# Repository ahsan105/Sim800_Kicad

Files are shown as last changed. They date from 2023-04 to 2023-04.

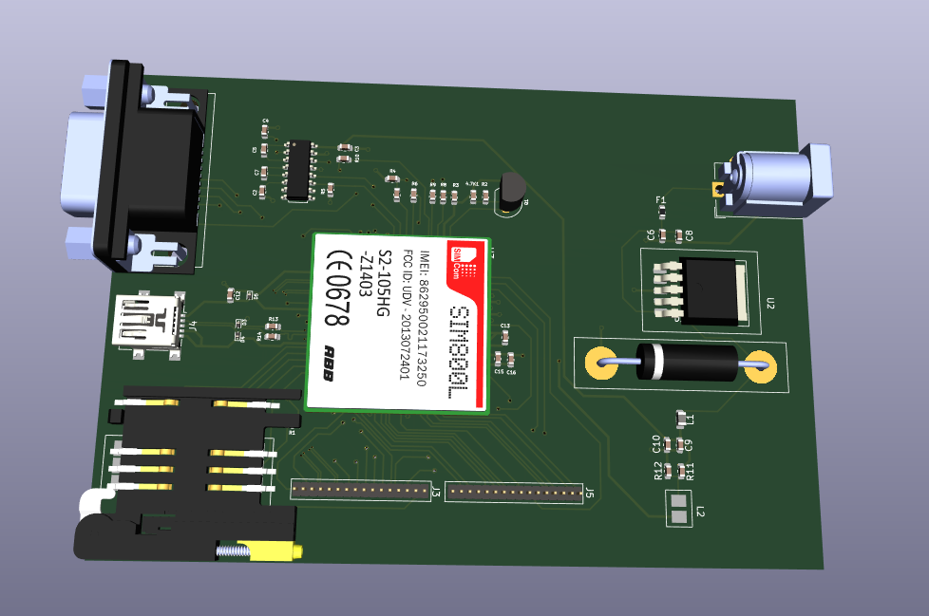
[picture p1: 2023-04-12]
3D_Image_of_project.png

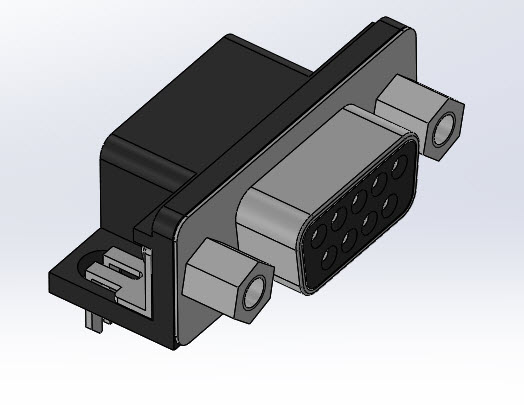
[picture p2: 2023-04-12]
db9-rs232-1.snapshot.3/Renderings/12-10-2558 9-55-57.jpg

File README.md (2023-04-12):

# Sim800_Kicad
This project is a hobby project (make sure you read the Readme file). The board hosts Sim800 IC that provides the GPRS capabilities to the board and added different 
serial protocols to provide ease of connection. Also the board has a power supply design that converts the output to 4.4V that goes to the IC.

Dont use this board directly. Make sure you consult your fabricator and change the clearance of differential pairs and also thickness.

Consult your fabricator and according to that set the via size and annular ring. 

Adjust the soldermask and other layers spacing according to it. 

Add an ESD peotection with sim interface.

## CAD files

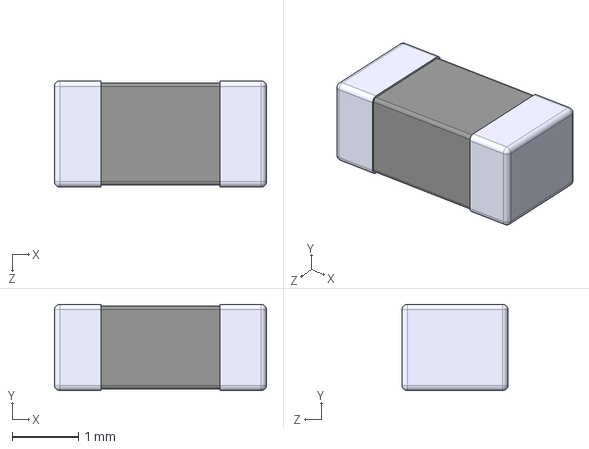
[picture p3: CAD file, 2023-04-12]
BLM31PG121SN1L/BLM31PG121SN1L.step
3.20 x 1.30 x 1.60 mm

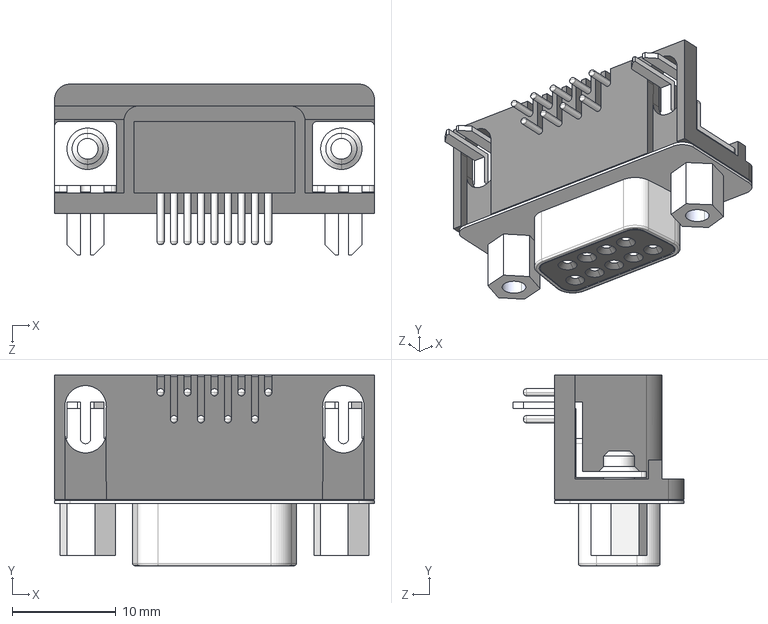
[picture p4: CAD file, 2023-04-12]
db9-rs232-1.snapshot.3/DB9.STEP
30.9 x 18.4 x 16.5 mm

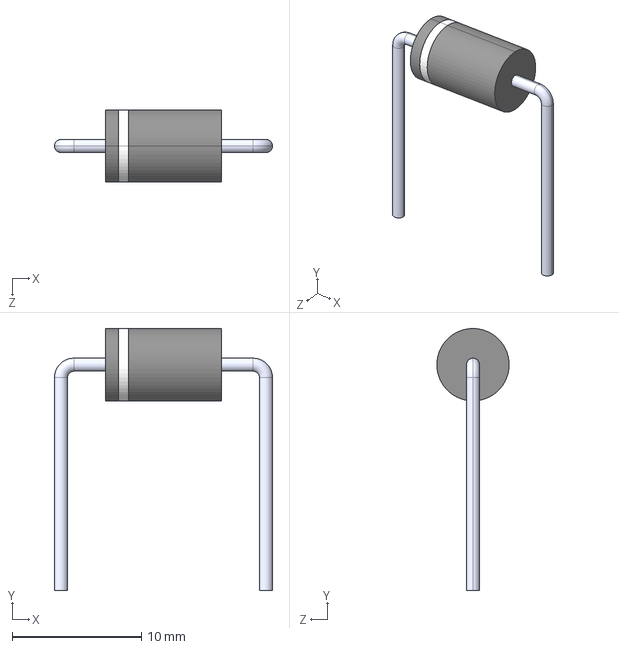
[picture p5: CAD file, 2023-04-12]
MBR360.STEP
16.9 x 20.3 x 5.60 mm

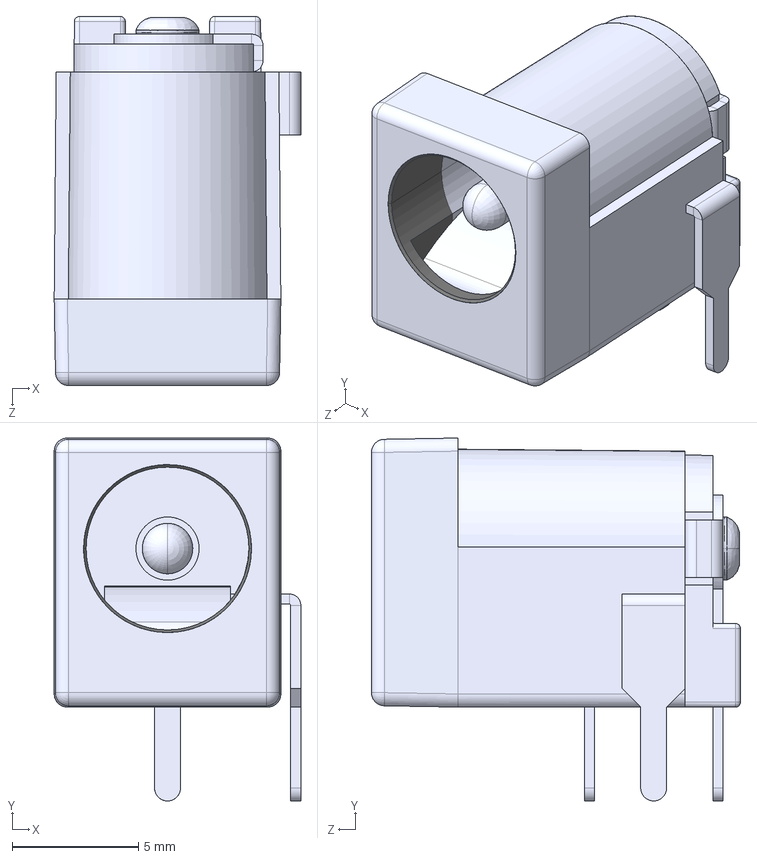
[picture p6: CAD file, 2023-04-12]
DC Power Jack 5.5mm x 2.1mm.IGS
9.77 x 14.4 x 14.6 mm

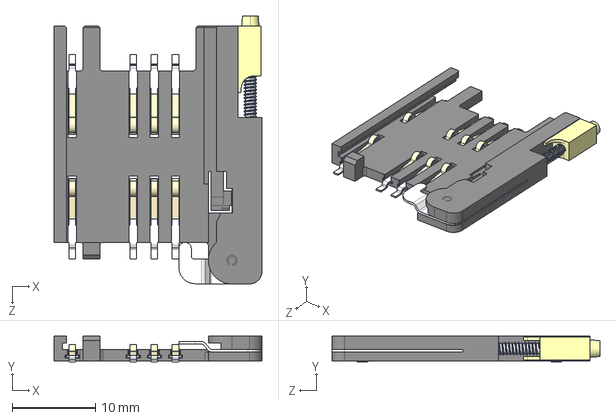
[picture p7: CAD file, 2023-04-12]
91228-3001--3DModel-STEP-56544.STEP
25.0 x 3.10 x 32.2 mm

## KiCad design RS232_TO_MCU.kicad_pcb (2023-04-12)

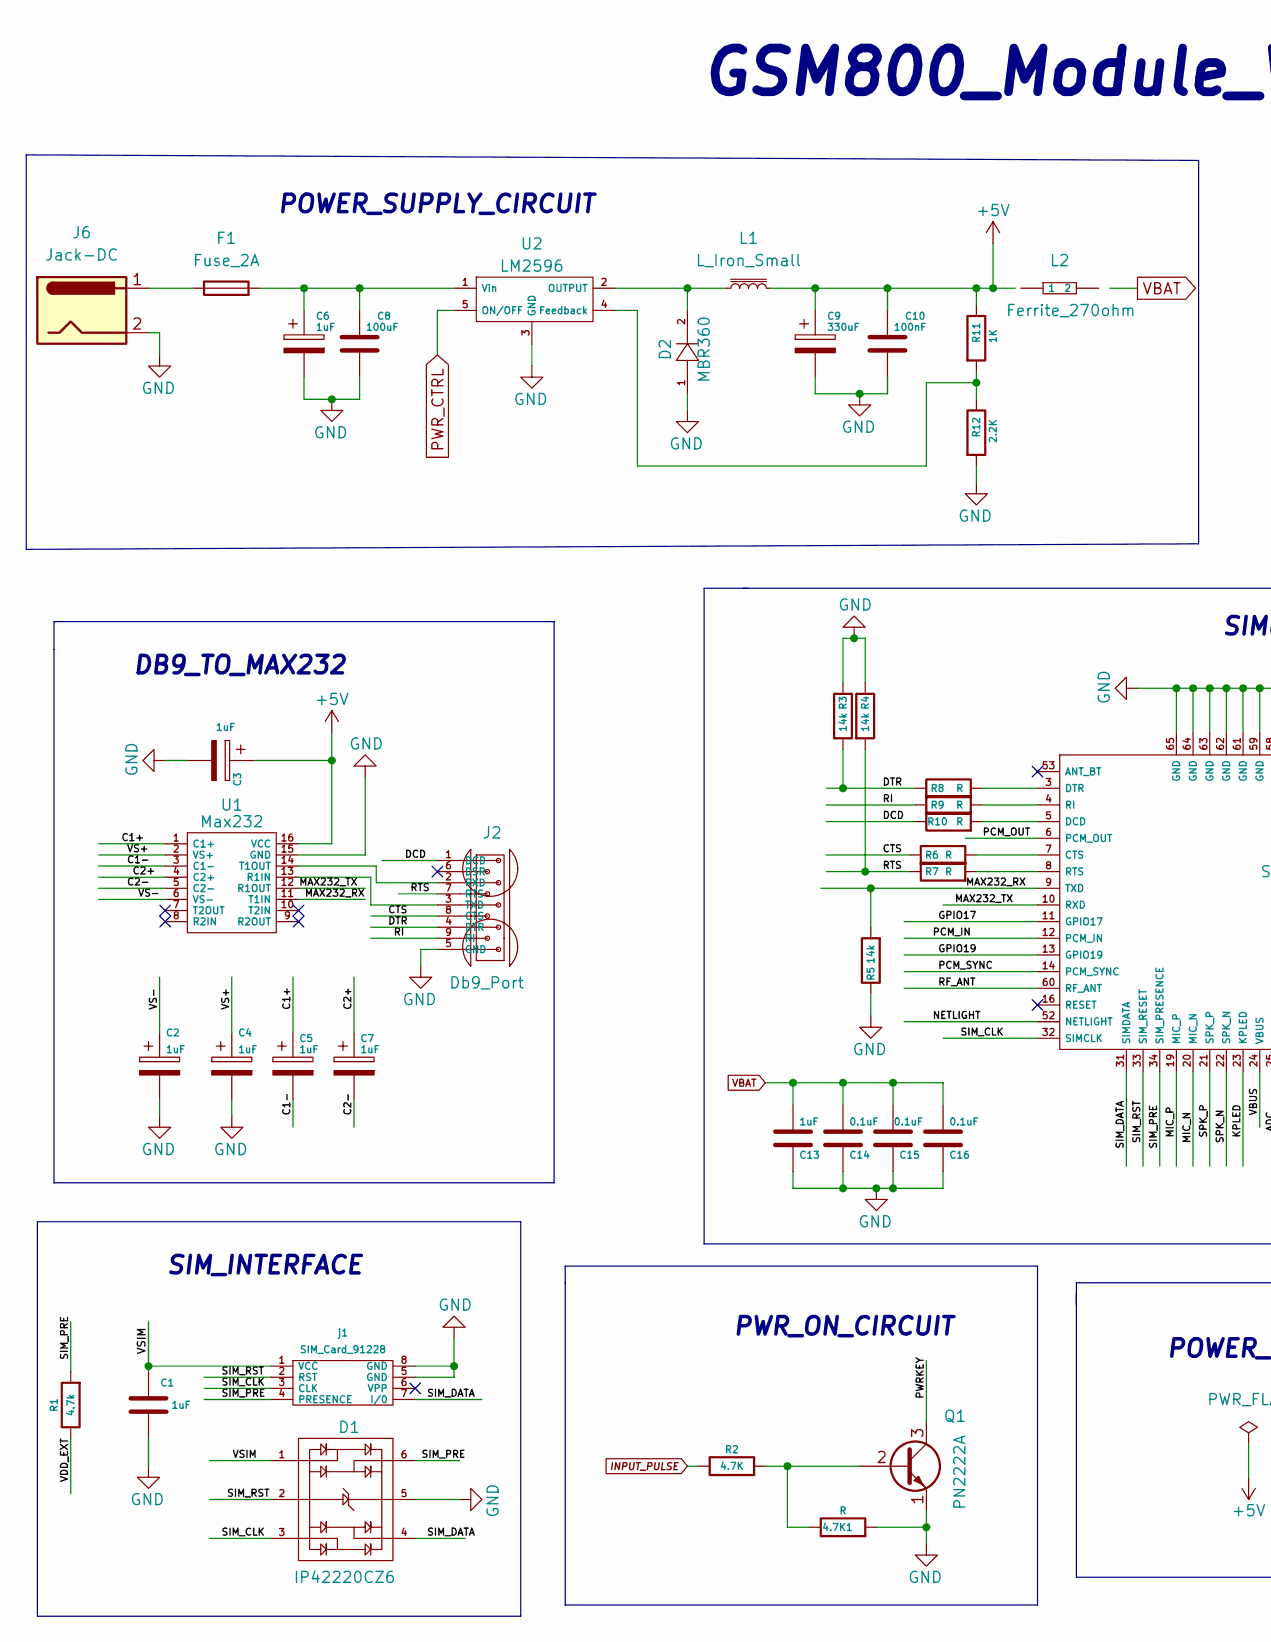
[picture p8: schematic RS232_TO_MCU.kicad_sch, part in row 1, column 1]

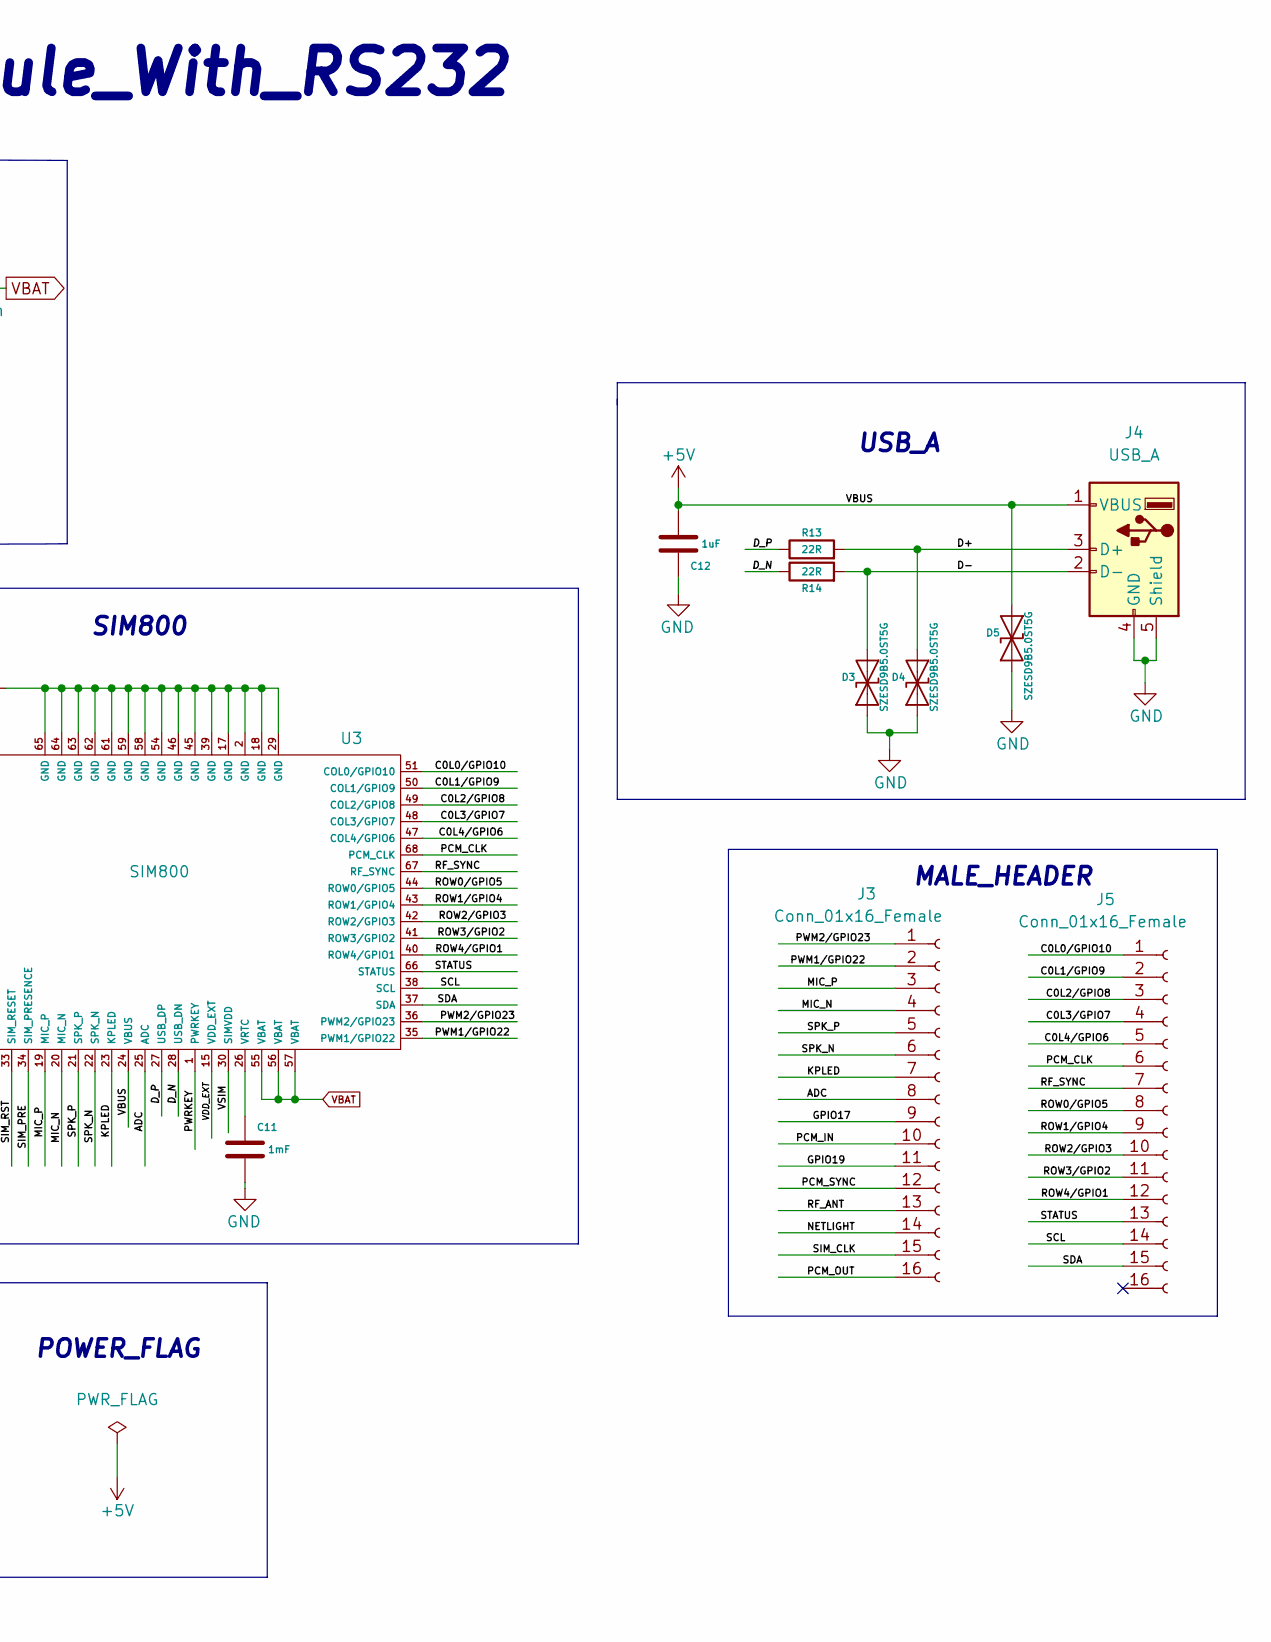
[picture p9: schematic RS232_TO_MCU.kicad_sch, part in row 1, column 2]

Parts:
4.7K1: R; C_0603_1608Metric
C1, C2, C3, C4, C5, C6, C7, C12, C13: 1uF; C_0603_1608Metric
C8: 100uF; C_0603_1608Metric
C9: 330uF; C_0603_1608Metric
C10: 100nF; C_0603_1608Metric
C11: 1mF; C_0603_1608Metric
C14, C15, C16: 0.1uF; C_0603_1608Metric
D1: IP42220CZ6
D2: MBR360
D3, D4, D5: SZESD9B5.0ST5G; D_SOD-923
F1: Fuse_2A; Fuse_0603_1608Metric
J2: Db9_Port; Db9
J3, J5: Conn_01x16_Female; Header_1x16
J4: USB_A; USB_Mini-B_Lumberg_2486_01_Horizontal
J6: Jack-DC; BarrelJack_CUI_PJ-102AH_Horizontal
L1: L_Iron_Small; L_0805_2012Metric
L2: Ferrite_270ohm; Ferrite_bead
Q1: PN2222A; TO-92_Inline
R1: 4.7k; C_0603_1608Metric
R2: 4.7K; C_0603_1608Metric
R3, R4, R5: 14k; C_0603_1608Metric
R6, R7, R8, R9, R10: R; C_0603_1608Metric
R11: 1K; C_0603_1608Metric
R12: 2.2K; C_0603_1608Metric
R13, R14: 22R; C_0603_1608Metric
U1: Max232; max232
U2: LM2596
U3: SIM800
j1: SIM_Card_91228; SimCard_91228

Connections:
+5V: C3.1, C9.1, C10.1, C12.2, D5.2 (A2), J4.1 (VBUS), L1.2, R11.1, U1.16 (VCC), U3.24 (VBUS)
/ADC: J3.8, U3.25 (ADC)
/C0L0/GPIO10: J5.1, U3.51 (COL0/GPIO10)
/C0L1/GPIO9: J5.2, U3.50 (COL1/GPIO9)
/C0L2/GPIO8: J5.3, U3.49 (COL2/GPIO8)
/C0L3/GPIO7: J5.4, U3.48 (COL3/GPIO7)
/C0L4/GPIO6: J5.5, U3.47 (COL4/GPIO6)
/C1+: C5.1, U1.1 (C1+)
/C1-: C5.2, U1.3 (C1-)
/C2+: C7.1, U1.4 (C2+)
/C2-: C7.2, U1.5 (C2-)
/CTS: J2.8 (CTS), R6.1
/D+: D4.2 (A2), J4.3 (D+), R13.2
/D-: D3.2 (A2), J4.2 (D-), R14.2
/DCD: J2.1 (DCD), R10.1
/DTR: J2.4 (DTR), R3.2, R8.1
/D_N: R14.1, U3.28 (USB_DN)
/D_P: R13.1, U3.27 (USB_DP)
/GPIO17: J3.9, U3.11 (GPIO17)
/GPIO19: J3.11, U3.13 (GPIO19)
/KPLED: J3.7, U3.23 (KPLED)
/MAX232_RX: R5.2, U1.11 (T1IN), U3.9 (TXD)
/MAX232_TX: U1.12 (R1OUT), U3.10 (RXD)
/MIC_N: J3.4, U3.20 (MIC_N)
/MIC_P: J3.3, U3.19 (MIC_P)
/NETLIGHT: J3.14, U3.52 (NETLIGHT)
/PCM_CLK: J5.6, U3.68 (PCM_CLK)
/PCM_IN: J3.10, U3.12 (PCM_IN)
/PCM_OUT: J3.16, U3.6 (PCM_OUT)
/PCM_SYNC: J3.12, U3.14 (PCM_SYNC)
/PWM1/GPIO22: J3.2, U3.35 (PWM1/GPIO22)
/PWM2/GPIO23: J3.1, U3.36 (PWM2/GPIO23)
/PWRKEY: Q1.3 (C), U3.1 (PWRKEY)
/RF_ANT: J3.13, U3.60 (RF_ANT)
/RF_SYNC: J5.7, U3.67 (RF_SYNC)
/RI: J2.9 (RI), R9.1
/ROW0/GPIO5: J5.8, U3.44 (ROW0/GPIO5)
/ROW1/GPIO4: J5.9, U3.43 (ROW1/GPIO4)
/ROW2/GPIO3: J5.10, U3.42 (ROW2/GPIO3)
/ROW3/GPIO2: J5.11, U3.41 (ROW3/GPIO2)
/ROW4/GPIO1: J5.12, U3.40 (ROW4/GPIO1)
/RTS: J2.7 (RTS), R4.2, R7.1
/SCL: J5.14, U3.38 (SCL)
/SDA: J5.15, U3.37 (SDA)
/SIM_CLK: D1.3, J3.15, U3.32 (SIMCLK), j1.3 (CLK)
/SIM_DATA: D1.4, U3.31 (SIMDATA), j1.7 (I/0)
/SIM_PRE: D1.6, R1.2, U3.34 (SIM_PRESENCE), j1.4 (PRESENCE)
/SIM_RST: D1.2, U3.33 (SIM_RESET), j1.2 (RST)
/SPK_N: J3.6, U3.22 (SPK_N)
/SPK_P: J3.5, U3.21 (SPK_P)
/STATUS: J5.13, U3.66 (STATUS)
/VDD_EXT: R1.1, U3.15 (VDD_EXT)
/VS+: C4.1, U1.2 (VS+)
/VS-: C2.1, U1.6 (VS-)
/VSIM: C1.1, D1.1, U3.30 (SIMVDD), j1.1 (VCC)
GND: 4.7K1.2, C1.2, C2.2, C3.2, C4.2, C6.2, C8.2, C9.2, C10.2, C11.2, C12.1, C13.1, C14.1, C15.1, C16.1, D1.5, D2.1, D3.1 (A1), D4.1 (A1), D5.1 (A1), J2.5 (GND), J4.4 (GND), J4.5 (Shield), J6.2, Q1.1 (E), R3.1, R4.1, R5.1, R12.2, U1.15 (GND), U2.3 (GND), U3.2 (GND), U3.17 (GND), U3.18 (GND), U3.29 (GND), U3.39 (GND), U3.45 (GND), U3.46 (GND), U3.54 (GND), U3.58 (GND), U3.59 (GND), U3.61 (GND), U3.62 (GND), U3.63 (GND), U3.64 (GND), U3.65 (GND), j1.5 (GND), j1.8 (GND)
INPUT_PULSE: R2.1
unnamed: 4.7K1.1, Q1.2 (B), R2.2
unnamed: C6.1, C8.1, F1.2, U2.1 (Vin)
unnamed: C11.1, U3.26 (VRTC)
unnamed: D2.2, L1.1, U2.2 (OUTPUT)
unnamed: F1.1, J6.1
unnamed: J2.2 (RXD), U1.14 (T1OUT)
unnamed: J2.3 (TXD), U1.13 (R1IN)
unnamed: R6.2, U3.7 (CTS)
unnamed: R7.2, U3.8 (RTS)
unnamed: R8.2, U3.3 (DTR)
unnamed: R9.2, U3.4 (RI)
unnamed: R10.2, U3.5 (DCD)
unnamed: L2.1, R11.2, R12.1, U2.4 (Feedback)
PWR_CTRL: U2.5 (ON/OFF)
VBAT: C13.2, C14.2, C15.2, C16.2, L2.2, U3.55 (VBAT), U3.56 (VBAT), U3.57 (VBAT)

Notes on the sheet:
MALE_HEADER
PWR_ON_CIRCUIT
SIM800
POWER_FLAG
SIM_INTERFACE
POWER_SUPPLY_CIRCUIT
GSM800_Module_With_RS232
DB9_TO_MAX232
USB_A

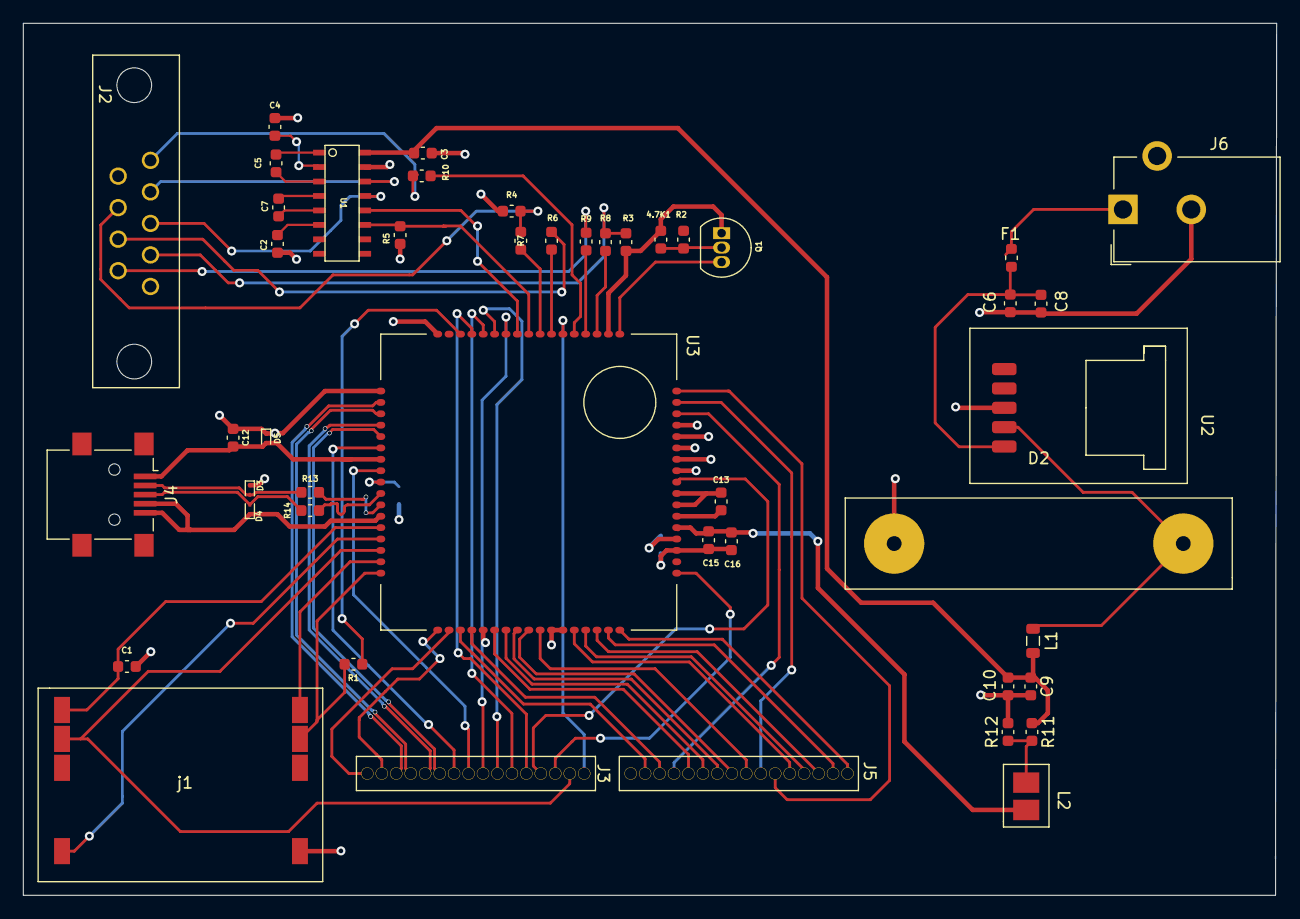
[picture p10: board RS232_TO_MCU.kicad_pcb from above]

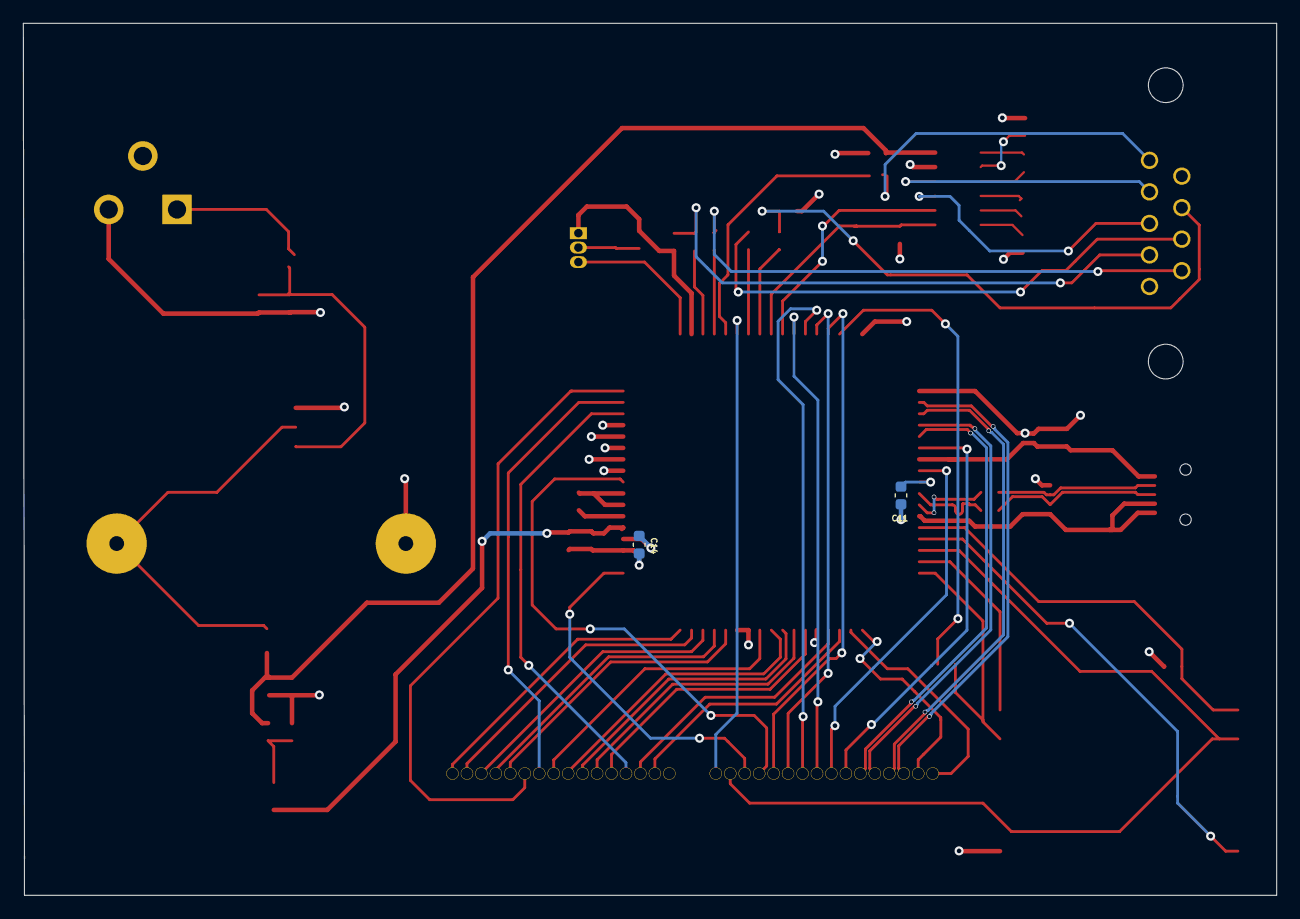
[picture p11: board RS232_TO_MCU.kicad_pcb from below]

Board: 4 copper layers, 110.1 x 76.6 mm, 48 parts (2 on the bottom side), 70 nets.
